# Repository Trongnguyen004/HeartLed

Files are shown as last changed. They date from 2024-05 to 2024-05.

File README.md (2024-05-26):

### HeartLed chưa được hoàn thiện 100% vì còn vướng về khâu tiết kiệm năng lượng vì sử dụng các pin CR2032, LIR2032, các loại pin có kích thước nhỏ mới phù hợp để làm 1 chiếc móc khóa.
### Vì giới hạn về mặt kiến thức lập trình nên hiện tại chưa thể can thiệp sâu vào các chế độ ngủ của chip. Vậy nên vấn đề trên sẽ được cải thiện dần trong thời gian tới.

### #Design 
<p align="center">
  <table>
    <tr>
      <td>
        
      </td>
      <td>
        
      </td>
      <td>
        
      </td>
    </tr>
  </table>
</p>

### #3D View
<p align="center">
  <table>
    <tr>
      <td>
        
      </td>
      <td>
        
      </td>
      <td>
        
      </td>
    </tr>
  </table>
</p>

### #Thành phẩm 
<p align="center">
  <table>
    <tr>
      <td>
        
      </td>
      <td>
        
      </td>
      <td>
        
      </td>
    </tr>
  </table>
</p>

### #Video
https://github.com/Trongnguyen004/HeartLed/assets/137270832/59e95ee1-c4d1-4318-9db8-90237cea7051

https://github.com/Trongnguyen004/HeartLed/assets/137270832/5ad59888-f046-4cde-adbe-0e13fbfc24e3

https://github.com/Trongnguyen004/HeartLed/assets/137270832/b6c706a9-fdab-4b93-9083-bb33e0925c82

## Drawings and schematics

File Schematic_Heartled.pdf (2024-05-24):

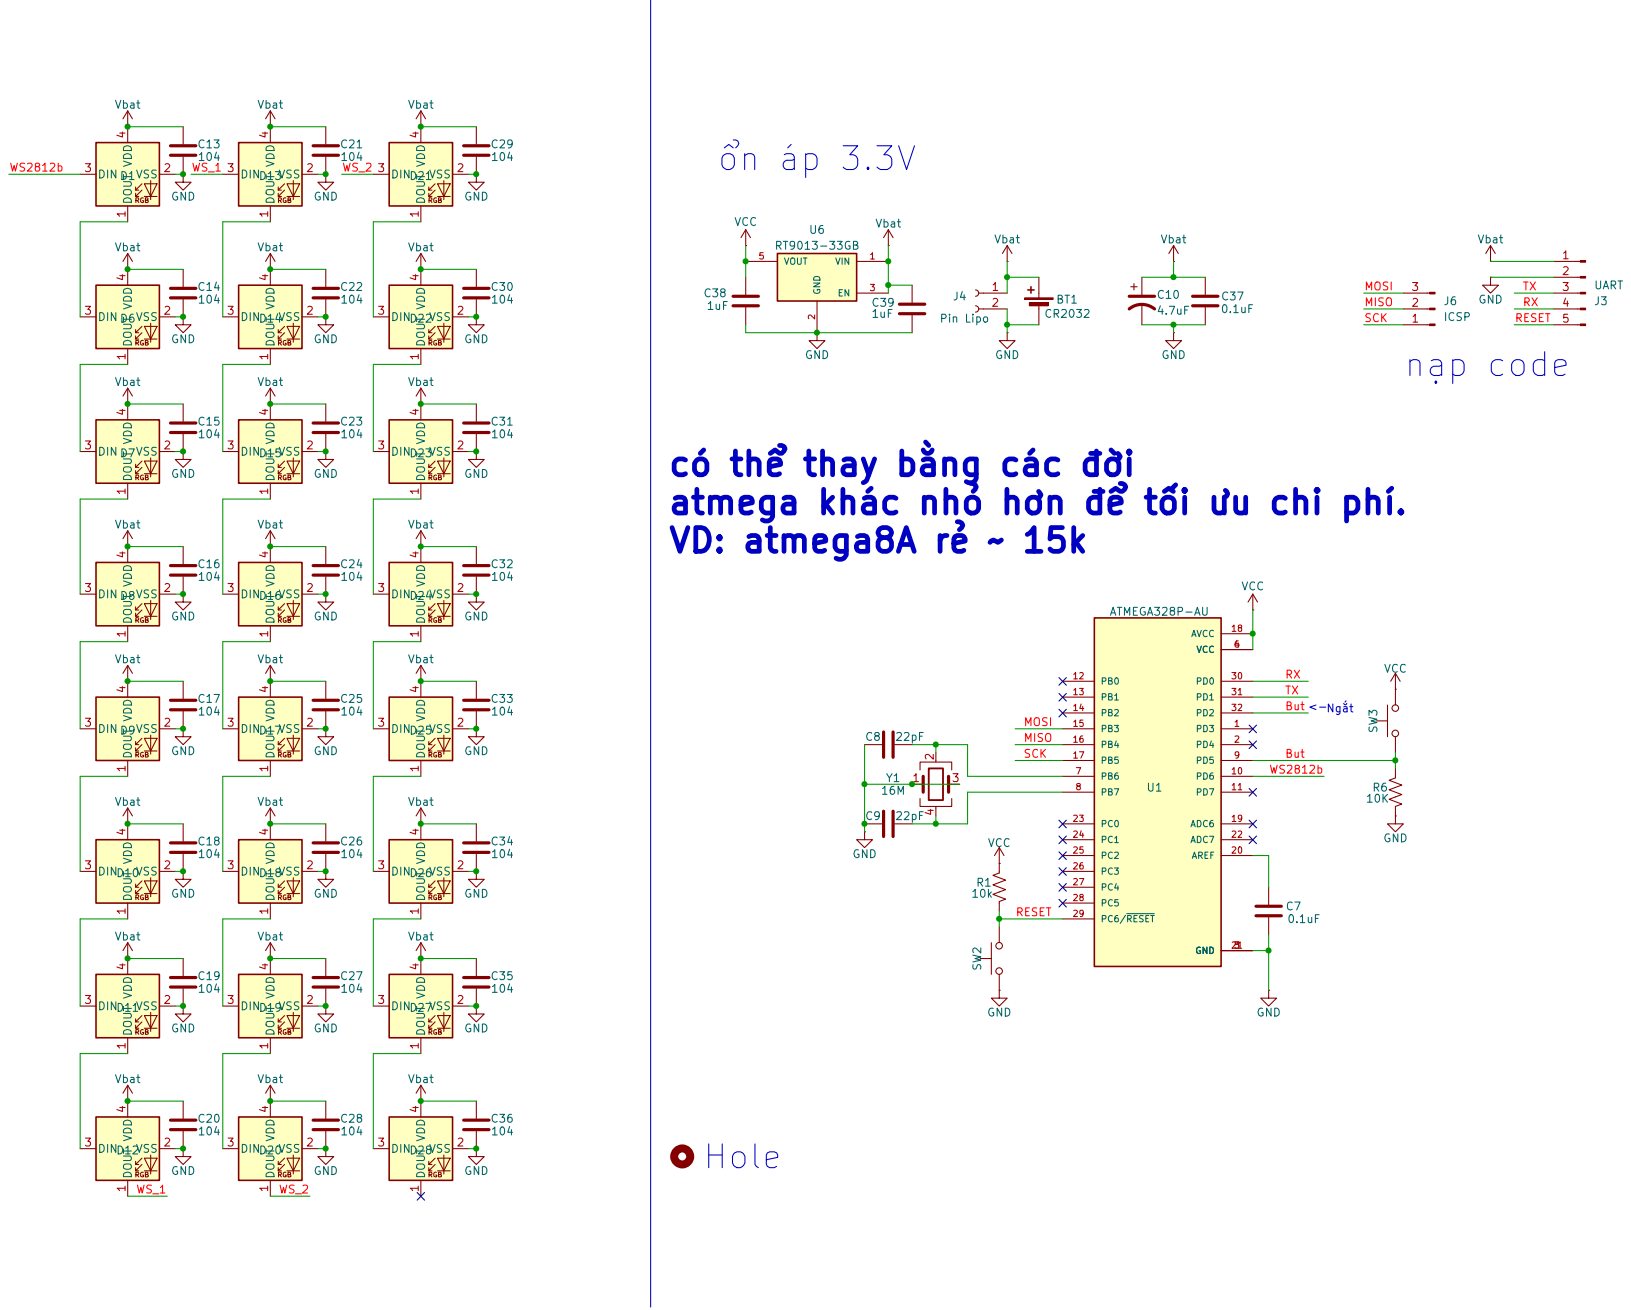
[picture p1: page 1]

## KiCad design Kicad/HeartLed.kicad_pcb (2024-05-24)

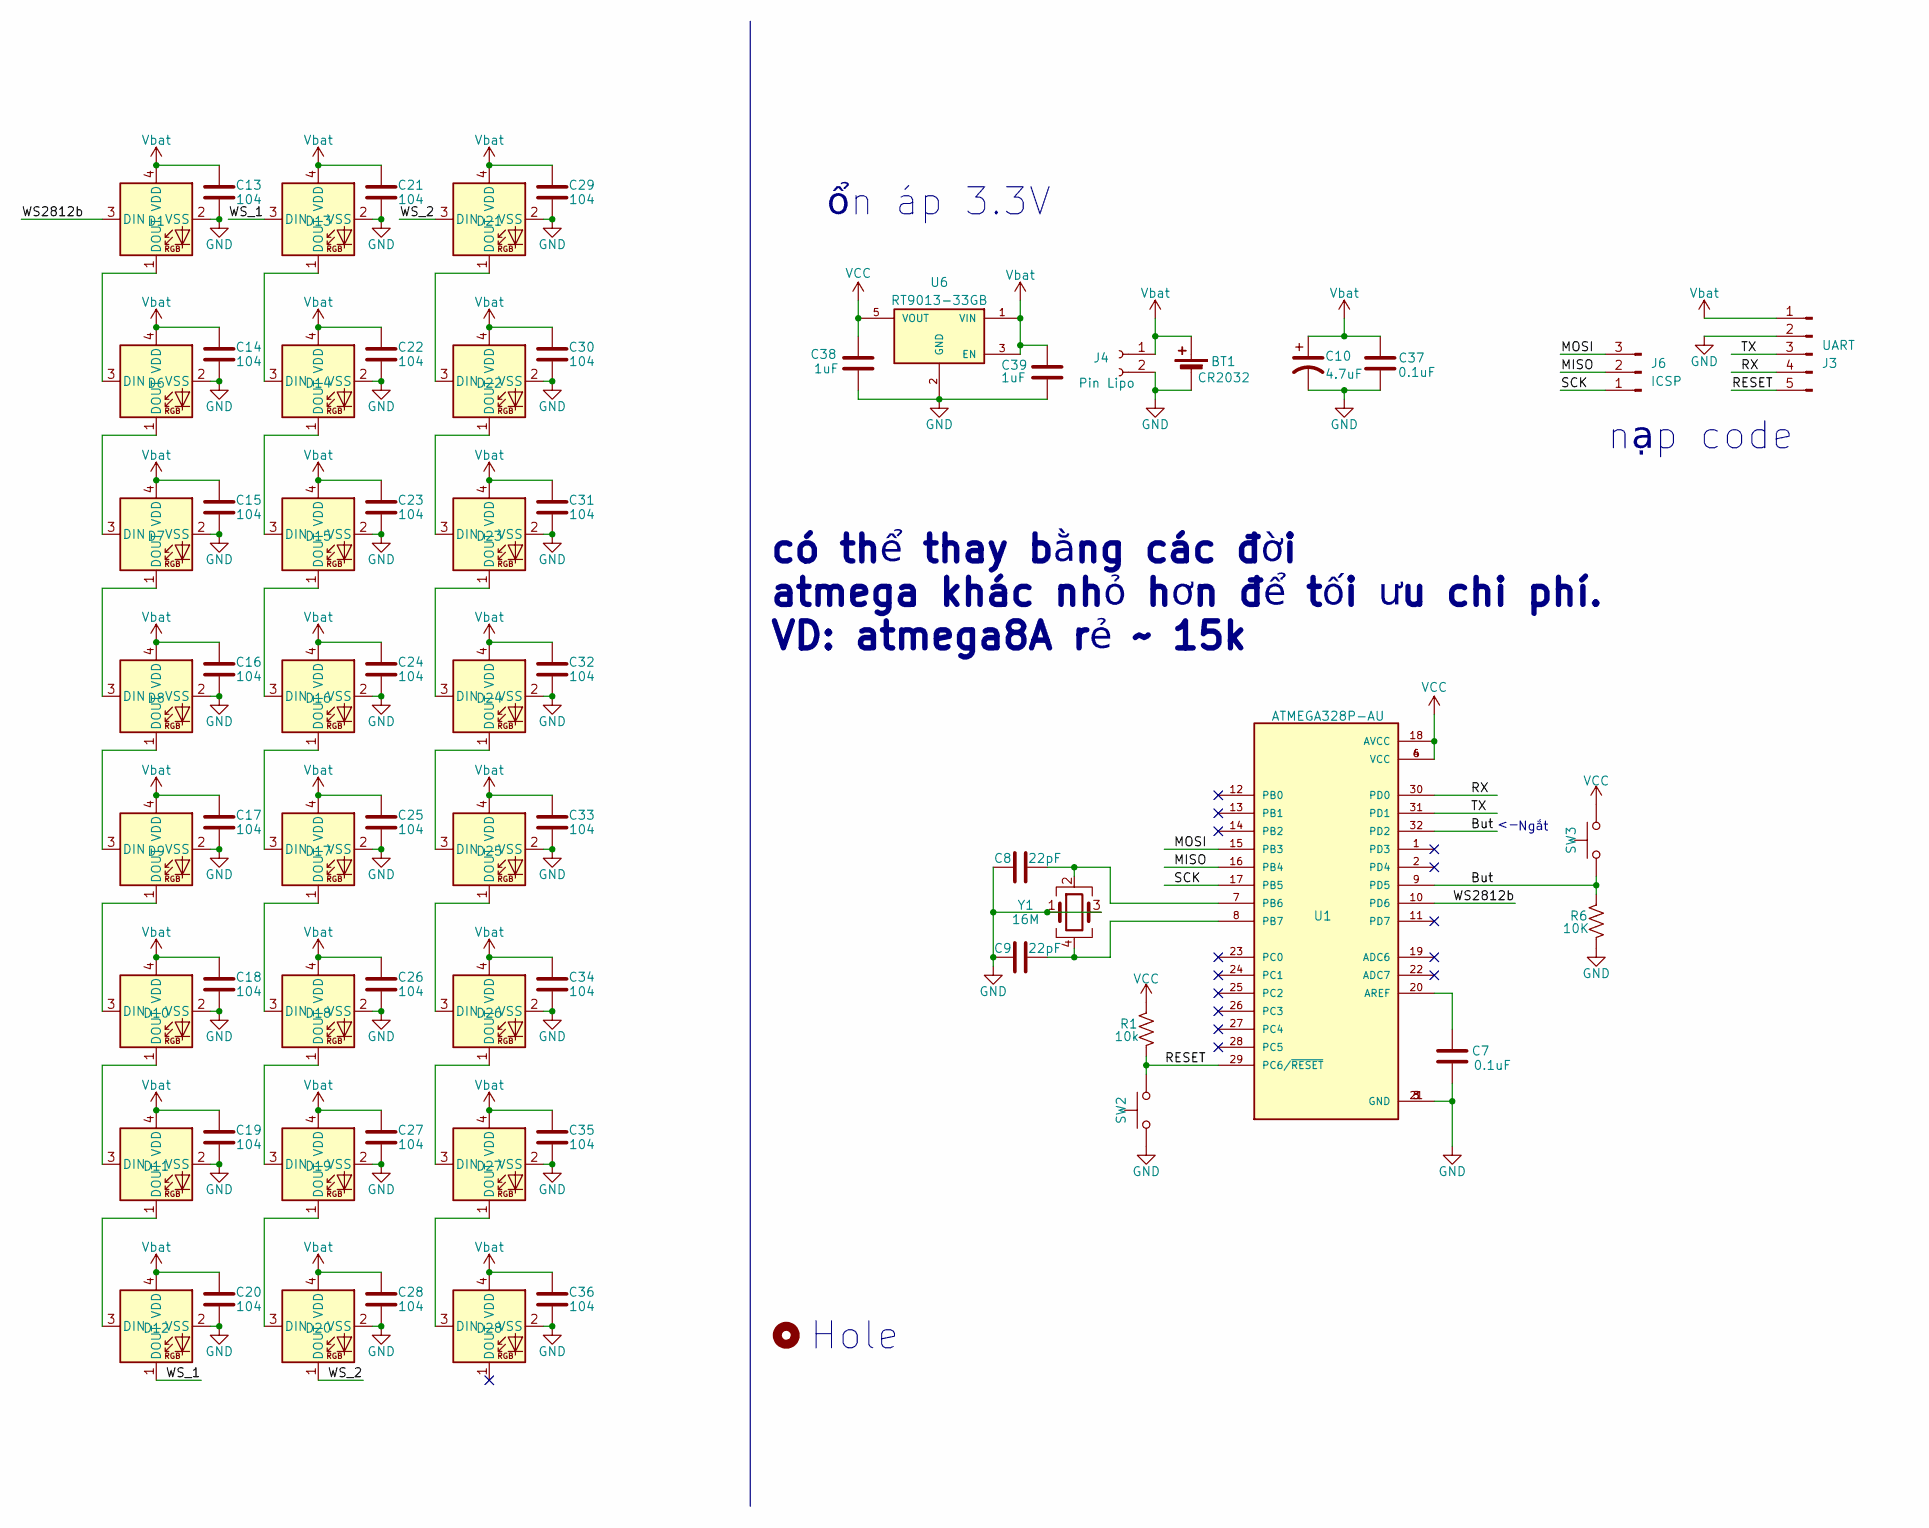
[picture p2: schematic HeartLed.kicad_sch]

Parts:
BT1: CR2032; BatteryHolder_MPD_BC2003_1x2032
C7, C37: 0.1uF; C_0603_1608Metric
C8, C9: 22pF; C_0805_2012Metric
C10: 4.7uF; CP_EIA-3216-18_Kemet-A_Pad1.58x1.35mm_HandSolder
C13, C14, C15, C16, C17, C18, C19, C20, C21, C22, C23, C24, C25, C26, C27, C28, C29, C30, C31, C32, C33, C34, C35, C36: 104; C_0603_1608Metric
C38, C39: 1uF; C_0805_2012Metric
D1, D6, D7, D8, D9, D10, D11, D12, D13, D14, D15, D16, D17, D18, D19, D20, D21, D22, D23, D24, D25, D26, D27, D28: WS2812B-2020; LED_WS2812B-2020_PLCC4_2.0x2.0mm
H1: HOLE; MountingHole_3.2mm_M3
J3: UART; PinHeader_1x05_P2.54mm_Vertical
J4: Pin Lipo; JST_B2B-XH-A_LF__SN_
J6: ICSP; PinHeader_1x03_P2.54mm_Vertical
R1: 10k; R_0603_1608Metric
R6: 10K; R_0603_1608Metric
SW2: RESET; SW_SPST_B3U-1000P
SW3: MODE; SW_Tactile_SPST_NO_Straight_CK_PTS636Sx25SMTRLFS
U1: ATMEGA328P-AU; QFP80P900X900X120-32N; PARTREV 8271A
U6: RT9013-33GB; SOT94P279X129-5N; PARTREV Aprill 2011
Y1: 16M; Crystal_SMD_3225-4Pin_3.2x2.5mm

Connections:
/But: R6.2, SW3.1, U1.9 (PD5), U1.32 (PD2)
/MISO: J6.2, U1.16 (PB4)
/MOSI: J6.3, U1.15 (PB3)
/RESET: J3.5, R1.1, SW2.2, U1.29 (PC6/~RESET)
/RX: J3.4, U1.30 (PD0)
/SCK: J6.1, U1.17 (PB5)
/TX: J3.3, U1.31 (PD1)
/WS2812b: D1.3 (DIN), U1.10 (PD6)
/WS_1: D12.1 (DOUT), D13.3 (DIN)
/WS_2: D20.1 (DOUT), D21.3 (DIN)
GND: BT1.2 (-), C7.1, C8.2, C9.2, C10.2, C13.1, C14.1, C15.1, C16.1, C17.1, C18.1, C19.1, C20.1, C21.1, C22.1, C23.1, C24.1, C25.1, C26.1, C27.1, C28.1, C29.1, C30.1, C31.1, C32.1, C33.1, C34.1, C35.1, C36.1, C37.1, C38.1, C39.1, D1.2 (VSS), D6.2 (VSS), D7.2 (VSS), D8.2 (VSS), D9.2 (VSS), D10.2 (VSS), D11.2 (VSS), D12.2 (VSS), D13.2 (VSS), D14.2 (VSS), D15.2 (VSS), D16.2 (VSS), D17.2 (VSS), D18.2 (VSS), D19.2 (VSS), D20.2 (VSS), D21.2 (VSS), D22.2 (VSS), D23.2 (VSS), D24.2 (VSS), D25.2 (VSS), D26.2 (VSS), D27.2 (VSS), D28.2 (VSS), J3.2, J4.2, R6.1, SW2.1, U1.3 (GND), U1.5 (GND), U1.21 (GND), U6.2 (GND), Y1.1, Y1.3
unnamed: D1.1 (DOUT), D6.3 (DIN)
unnamed: D6.1 (DOUT), D7.3 (DIN)
unnamed: D7.1 (DOUT), D8.3 (DIN)
unnamed: D8.1 (DOUT), D9.3 (DIN)
unnamed: D9.1 (DOUT), D10.3 (DIN)
unnamed: D10.1 (DOUT), D11.3 (DIN)
unnamed: D11.1 (DOUT), D12.3 (DIN)
unnamed: D13.1 (DOUT), D14.3 (DIN)
unnamed: D14.1 (DOUT), D15.3 (DIN)
unnamed: D15.1 (DOUT), D16.3 (DIN)
unnamed: D16.1 (DOUT), D17.3 (DIN)
unnamed: D17.1 (DOUT), D18.3 (DIN)
unnamed: D18.1 (DOUT), D19.3 (DIN)
unnamed: D19.1 (DOUT), D20.3 (DIN)
unnamed: D21.1 (DOUT), D22.3 (DIN)
unnamed: D22.1 (DOUT), D23.3 (DIN)
unnamed: D23.1 (DOUT), D24.3 (DIN)
unnamed: D24.1 (DOUT), D25.3 (DIN)
unnamed: D25.1 (DOUT), D26.3 (DIN)
unnamed: D26.1 (DOUT), D27.3 (DIN)
unnamed: D27.1 (DOUT), D28.3 (DIN)
unnamed: C7.2, U1.20 (AREF)
unnamed: C8.1, U1.7 (PB6), Y1.2
unnamed: C9.1, U1.8 (PB7), Y1.4
VCC: C38.2, R1.2, SW3.2, U1.4 (VCC), U1.6 (VCC), U1.18 (AVCC), U6.5 (VOUT)
Vbat: BT1.1 (+), C10.1, C13.2, C14.2, C15.2, C16.2, C17.2, C18.2, C19.2, C20.2, C21.2, C22.2, C23.2, C24.2, C25.2, C26.2, C27.2, C28.2, C29.2, C30.2, C31.2, C32.2, C33.2, C34.2, C35.2, C36.2, C37.2, C39.2, D1.4 (VDD), D6.4 (VDD), D7.4 (VDD), D8.4 (VDD), D9.4 (VDD), D10.4 (VDD), D11.4 (VDD), D12.4 (VDD), D13.4 (VDD), D14.4 (VDD), D15.4 (VDD), D16.4 (VDD), D17.4 (VDD), D18.4 (VDD), D19.4 (VDD), D20.4 (VDD), D21.4 (VDD), D22.4 (VDD), D23.4 (VDD), D24.4 (VDD), D25.4 (VDD), D26.4 (VDD), D27.4 (VDD), D28.4 (VDD), J3.1, J4.1, U6.1 (VIN), U6.3 (EN)

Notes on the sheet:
Hole
Ngắt
nạp code
có thể thay bằng các đời atmega khác nhỏ hơn để tối ưu chi phí. VD: atmega8A rẻ ~ 15k
ổn áp 3.3V

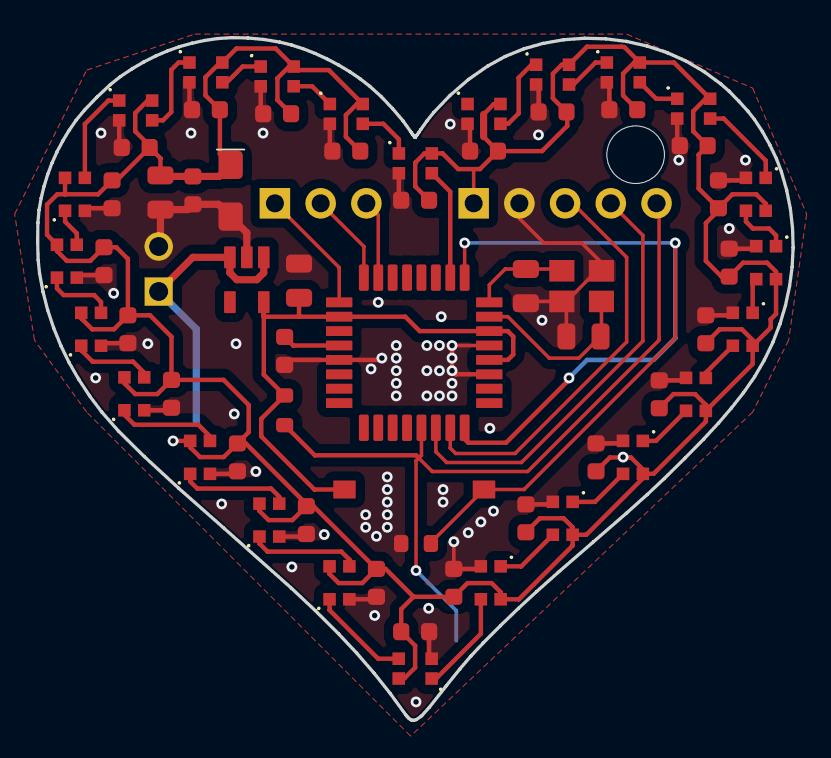
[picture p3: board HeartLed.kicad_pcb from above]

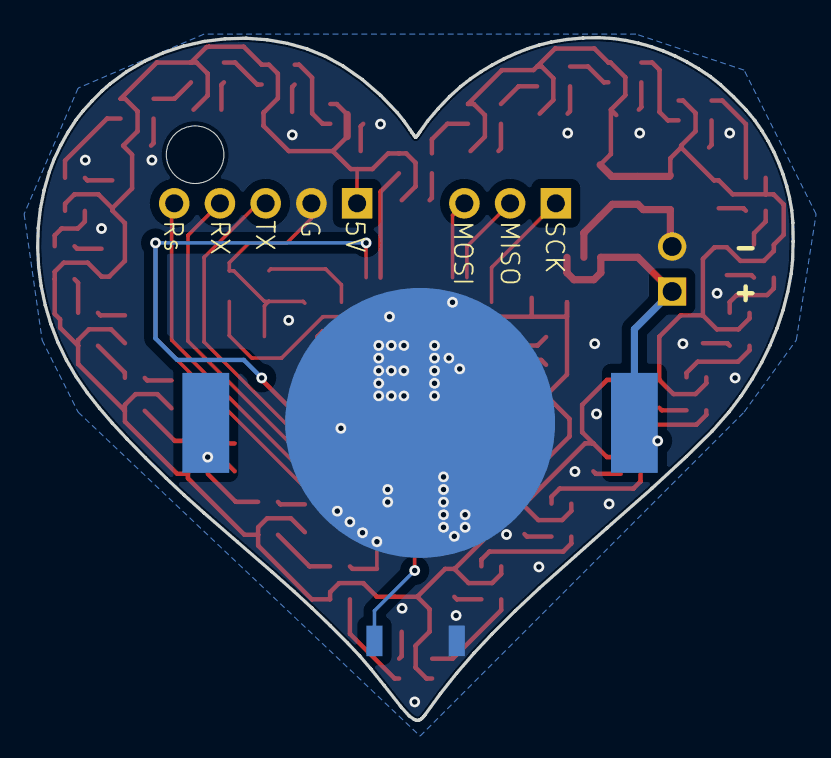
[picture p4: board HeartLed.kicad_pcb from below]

Board: 2 copper layers, 42.0 x 37.9 mm, 67 parts (3 on the bottom side), 37 nets.

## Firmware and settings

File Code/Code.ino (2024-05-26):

//----------------------------------------        HeardLed             -------------------------------------------------------
//--------------------------------------      Nguyễn Đức Trọng CKC      ------------------------------------------------------
//---------------------------------          //|         //////||           --------------------------------------------------
//---------------------------------         //||               ||           --------------------------------------------------
//---------------------------------        // ||         //////||           --------------------------------------------------
//---------------------------------           ||               ||           --------------------------------------------------
//---------------------------------           ||         //////||           --------------------------------------------------
//----------------          Code chuyển hiệu ứng bằng nút nhấn, mỗi hiệu ứng chạy 60s thì tắt     ----------------------------
#include <FastLED.h>
#include <LowPower.h>

#define NUM_LEDS  24
#define LED_PIN   6
#define BUT   5

#define BRIGHTNESS  20
#define dogiamsang  15
#define BUTTON_PIN 2
#define Time  30000

//CRGB leds[NUM_LEDS];
CRGBArray<NUM_LEDS> leds;
CRGB colors[] = { CRGB::Red, CRGB::Blue, CRGB::Green, CRGB::Magenta, CRGB::Cyan };

static uint8_t hue = 0;

unsigned long endTime ;
unsigned long thoigian;

volatile int currentEffect = 0;
volatile bool buttonPressed = false;

void setup(){
  FastLED.addLeds<WS2812B, LED_PIN, GRB>(leds, NUM_LEDS);
  FastLED.setBrightness(  BRIGHTNESS );
  pinMode(BUTTON_PIN, INPUT);
  pinMode(BUT, INPUT);
  attachInterrupt(digitalPinToInterrupt(BUTTON_PIN), changeEffect, RISING);
  tathieuung();
}

void loop() {
   if(thoigian < endTime){
     thoigian = millis();
     effect();    
   }else {
     tathieuung();
  }
}

void changeEffect() {
  if(digitalRead(BUT)){
    delay(170);
    currentEffect++;
    thoigian = millis();
    endTime = thoigian + Time;
    buttonPressed = true; 
    while(digitalRead(BUT)){}
  }    
}
//  RedToBlue_effect();
//  duoixenke(); 
 
//  cauvong();
//  pride();
//  rainbow();
//  sangtat();
//  sangdon();
//  xoaytron_doimau();
//  lenxuong_doimau();
//  xenkecauvong();
//  xenkedoimau();
//  duoi();

void effect(){
  buttonPressed = false; 
  switch (currentEffect) {
      case 0: tathieuung();                                              
                                              break;
      case 1: cauvong();                                        
                                              break;
      case 2: rainbow();                                        
                                              break;
      case 3: sangtat();                 
                                              break;
      case 4: FastLED.setBrightness(BRIGHTNESS );sangdon();                                            
                                              break;
      case 5: xoaytron_doimau();                                      
                                              break;
      case 6: lenxuong_doimau();                                         
                                              break;
      case 7: xenkecauvong();                                                
                                              break;
      case 8: pride();                                       
                                              break;
      case 9: xenkedoimau();                                                 
                                              break;
      case 10: duoi();                                                 
                                              break;
      default: currentEffect = 0;                                         
                                              break;
    }
}


void tathieuung() {
  fill_solid(leds, NUM_LEDS, CRGB::Black);
  FastLED.show();
  LowPower.powerDown(SLEEP_FOREVER, ADC_OFF, BOD_OFF);
}

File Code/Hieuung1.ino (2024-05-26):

///////////////////////////////////////////////////////////////////////////////////////////////////////////
void RedToBlue_effect(){
      for (int x = 0; x < NUM_LEDS ;x++){
        if (buttonPressed) return;
        leds[x] = CRGB::Blue;
        fadeToBlackBy(leds, NUM_LEDS, 10);
        FastLED.show();
        delay(50);
      }
      for (int x = NUM_LEDS ;x>=0 ;x--){
        if (buttonPressed) return;
        leds[x] = CRGB::Red;
        fadeToBlackBy(leds, NUM_LEDS, 10);
        FastLED.show();
        delay(50);  
      }    
}


///////////////////////////////////////////////////////////////////////////////////////////////////////////

void sangtat(){
  int numColors = sizeof(colors) / sizeof(colors[0]);  
  for (int colorIndex = 0; colorIndex < numColors; colorIndex++) {
    
    CRGB currentColor = colors[colorIndex];  
    for (int brightness = 0; brightness <= BRIGHTNESS; brightness++) {
      fill_solid(leds, NUM_LEDS, currentColor);
      FastLED.setBrightness(brightness);
      FastLED.show();
      FastLED.delay(70);
      if (buttonPressed) return;
    }  
    for (int brightness = BRIGHTNESS; brightness >= 0; brightness--) {
      fill_solid(leds, NUM_LEDS, currentColor);
      FastLED.setBrightness(brightness);
      FastLED.show();
      FastLED.delay(70);
      if (buttonPressed) return;
    }
    if (buttonPressed) return;
  }
  FastLED.setBrightness(BRIGHTNESS);
}
///////////////////////////////////////////////////////////////////////////////////////////////////////////
void cauvong() {
  for(int i = 0; i < NUM_LEDS; i++) {      
    if (buttonPressed) return;
    leds[i] = CHSV((hue - (i * 256 / NUM_LEDS)) % 256, 255, 255);
  }
  hue++;
  FastLED.show();
  delay(5); 
}
